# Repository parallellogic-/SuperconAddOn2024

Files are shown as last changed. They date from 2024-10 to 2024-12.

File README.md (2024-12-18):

# Luna Says Supercon Add-On Overview

This repo contains the project files for a Supercon Add-On (SAO) Printed Circuit Board (PCB) for Hackaday Supercon 2024, held November 1-3rd in Pasadena.

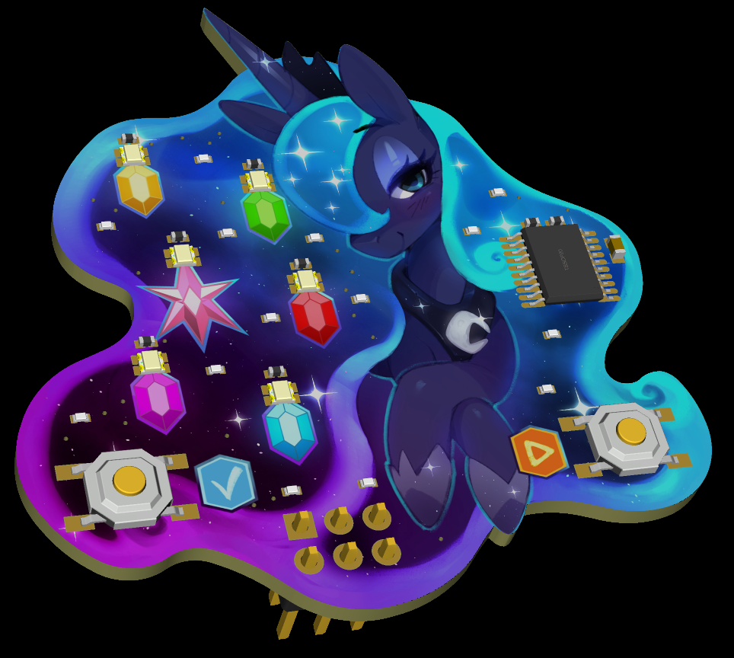
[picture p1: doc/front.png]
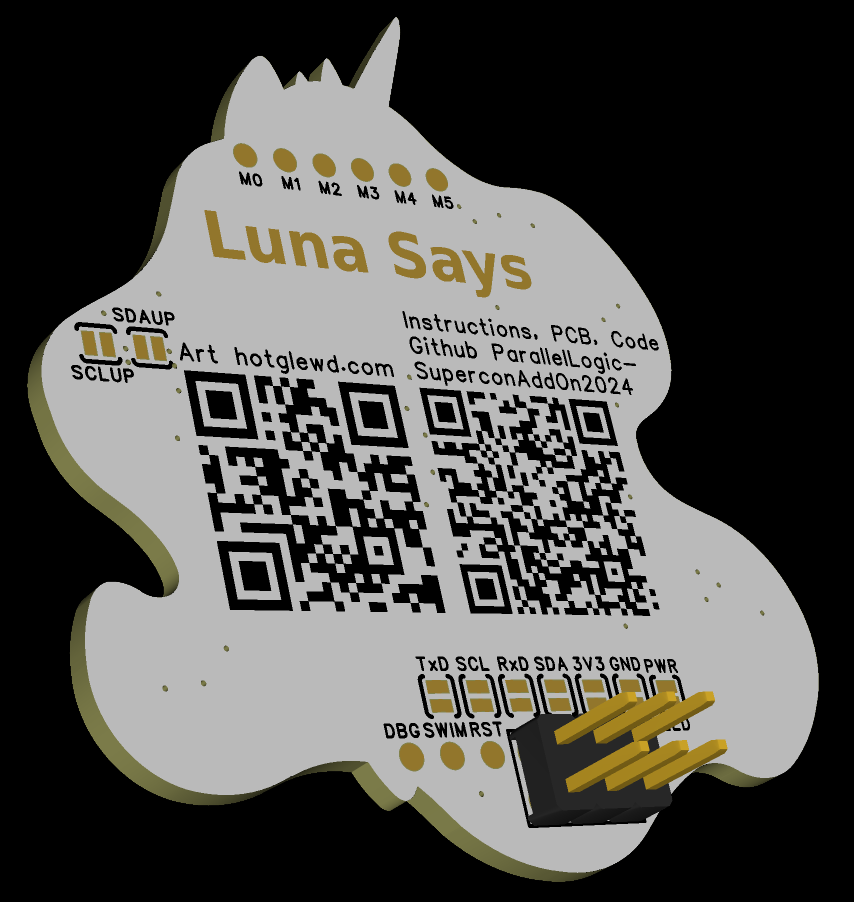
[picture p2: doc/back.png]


# User Guide

By default, when the unit is powered ON, the LEDs will display a random screen-saver display pattern on the white LEDs.

Pressing either button enters into a "Luna Says" game:
- Luna will highlight one of the Elements of Harmony (RGB LEDs)
- You must repeat the pattern that Luna has shown.  Press the right button to move the cursor and the left button to select the same Element of Harmony.
- When you highlight the correct gem, Luna's mane will flash green and she will then highlight one more gem than before.
- You must then highlight the same gems in the same order with progressively longer patterns.
- If you fail to repeat the pattern correctly, the LEDs will flash red and the game will reset from the beginning.
- The game is won by highlighting all the Elements of Harmony

Long pressing either button will enter in a Cyclone game:
- The Element of Harmony will spin in a circle
- You must press either button the moment the element passes the white marker
- When timed correctly, the central marker and two neighboring LEDs will alternately blink.  Pressing the button again will start the next (faster) level
- Failing to time the press accurately will flash the LED where the cursor landed.  Pressing the button again will restart the current level.
- The game is won by clearing all 6 levels

# Examples

## Idle

Random screen-saver idle display pattern



## Luna Says

Luna highlights the Elements of Harmony in a specific order.  You must repeat her pattern.

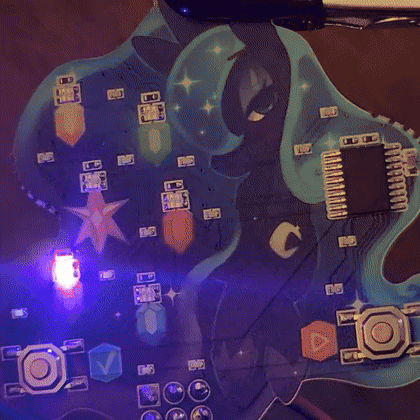
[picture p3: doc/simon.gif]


## Cyclone

The Elements of Harmony spin and you must catch each one at the right moment

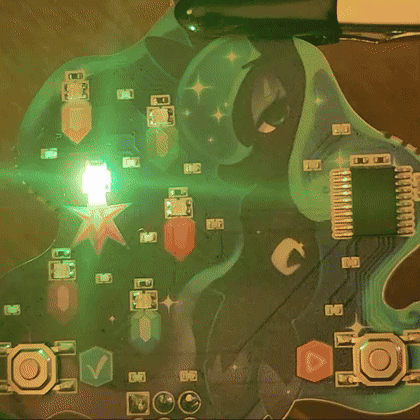
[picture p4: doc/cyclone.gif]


# Design

The state of the SAO may be read (buttons) and written (LEDs) using the I2C serial connection.

There are 6 pins on the SAO interface.  Two are used for 3V3 and GND power input.  Two are used for I2C.  The remaining two serve as SAO output event flags for button and frame-render-complete events.

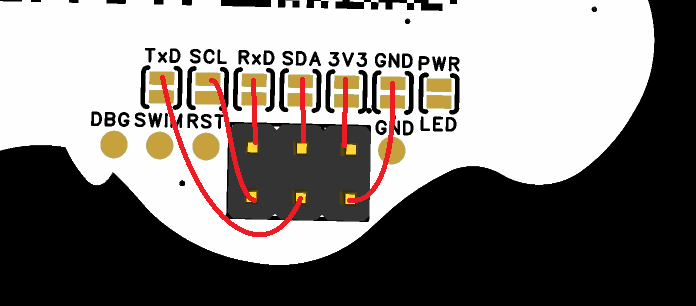
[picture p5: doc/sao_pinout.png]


| Pinout | | |
|---|-----|-----|
| GPIO1  | SDA | 3V3 |
| GPIO0  | SCL | GND |

The routing of the interface signals on the SAO header may be re-directed by cutting the associated trace and soldering jumper wires to the desired configuration.  The example below shows cutting (ex. with an exacto knife) the SDA and SCL traces (red) and then soldering jumper wires to swap the SDA and SCL lines (green and blue) on the I2C bus.

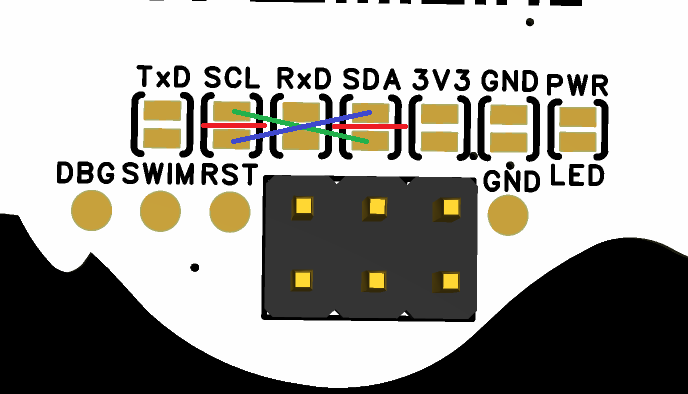
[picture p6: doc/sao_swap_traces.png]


Soldering the "PWR" jumper closed will permanently turn ON the dedicated power LED.

The I2C data and clock lines each have a 10kohm pull up resistor to 3V3 connected.  This can be disabled by cutting the traces here:

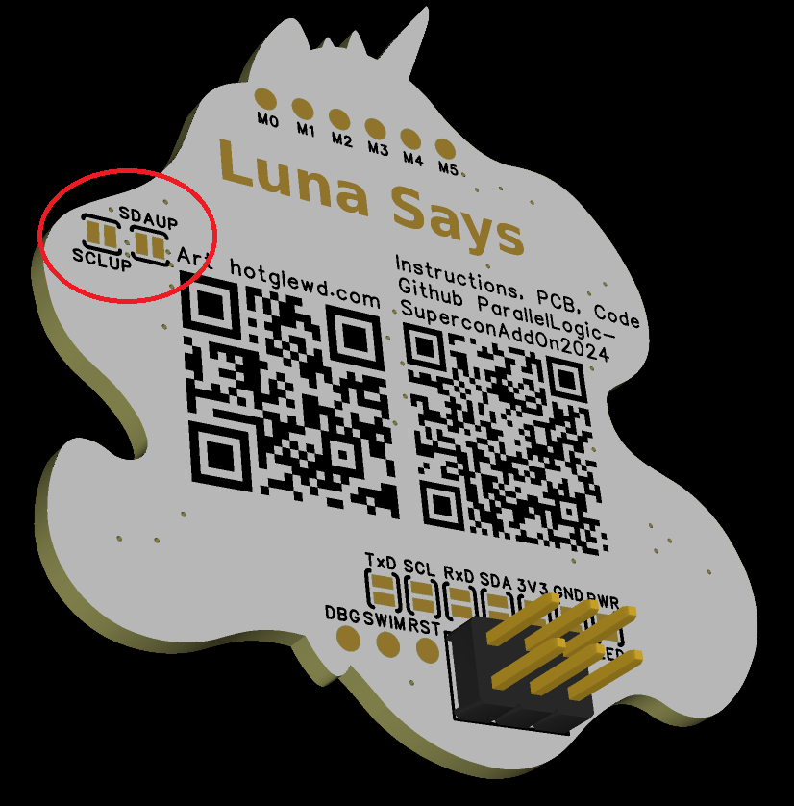
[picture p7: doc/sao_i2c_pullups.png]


There are two buttons and 31 LEDs (the RGB LED consists of three colors each that can be individually controlled).  30 of the LEDs are driven by 6 pins in a charlieplexed configuration.  The remaining debug LED, buttons, and serial interface are assigned dedicated pins on the processor.

| | 0 | 1 | 2 | 3 | 4 | 5 | Positive |
|---|---:|---:|---:|---:|---:|---:|---|
| 0 | | 20 (w7)  | 21 (w8)  | 4 (r4) | 5 (r5) | 6 (r6) | |
| 1 | 22 (w9)  | | 23 (w10) | 10 (g4)  | 11 (g5)  | 12 (g6)  | |
| 2 | 24 (w11) | 25 (w12) | | 16 (b4)  | 17 (b5)  | 18 (b6)  | |
| 3 | 1 (r1) | 2 (r2) | 3 (r3) | | 26 (w13) | 27 (w14) | |
| 4 | 7 (g1) | 8 (g2) | 9 (g3) | 28 (w15) | | 29 (w16) | |
| 5 | 13 (b1)  | 14 (b2)  | 15 (b3)  | 30 (w17) | 31 (w18) | | |
| Negative | | | | | | | |

| | PORT | PIN |
|---|---|-----|
| MAT0  | C | 3 |
| MAT1  | C | 4 |
| MAT2  | C | 5 |
| MAT3  | C | 6 |
| MAT4  | C | 7 |
| MAT5  | D | 2 |
| DEBUG | A | 3 |
| BTN0  | D | 3 |
| BTN1  | D | 4 |
| SWIM  | D | 1 |

# API

An example program that interfaces with the SAO over I2C (reading button state and setting LEDs) can be found [here](/src/Arduino_I2C_Master/Arduino_I2C_Master.ino)

SAO device 7-bit address is 0x30.  The baud rate is 100 kHz.

| Register Map | R/W | Title | Default | Range, Inclusive | Notes |
|:---:|:---:|:---:|:---:|:---:|:---:|
| 0 | R/W | Dummy | 0 | 0x00-0xFF | Values written here will echo back the same when read.  Reading this register will toggle the state of the debug LED. |
| 1 | R/W | Write Count | 0 | 0x00-0xFF | Counter of the number of I2C write transactions since power ON, value will roll-over above 0xFF.  Each read consists of 2 operations: a write (setting the register address) and a read (fetching the register contents) |
| 2 | R/W | Read Count | 0 | 0x00-0xFF | Number of I2C read transactions since power ON |
| 3 | W | LED Index | 0 | 0x00-0x1F | Writing an odd (>2) number of bytes to this register in single transaction is the same as writing alternately to registers 3 and 4,  with the final byte being written to register 5 |
| 4 | W | LED Brightness | 0 | 0x00-0xFF | 0 is OFF, 0xFF is max |
| 5 | W | Effective LED Count and LED Buffer Flush | 0 | 0x00-0x10 | Higher values are possible, but cause LED flickering and latency with button events |
| 6 | R/W | Button Interrupt Config | 0x03 | 0x00-0x03 | 0x01 (LSB) set to 1 means GPIO0 will be HIGH the moment the buttons are pressed (instantaneous), 0x02 set to 1 means GPIO0 will go high any  time there is a button event ready (short or long on the left or right  button).  0x03 sets GPIO0 HIGH any time either condition is true. If no  interrupt is triggered, then the pin is driven LOW.  Note: on first  power ON, until a valid I2C command is received, this pin floats |
| 7 | R | Peek button events | 0 | 0x00-0xF7 | 0x01 (LSB) is left button instantaneously down (0 is unpressed), 0x02 is right button instantaneously down, 0x04 is SWIM pin, 0x08 is unused, 0x10 is short press event flag on left button, 0x20 is short press on right button flag, 0x40 is long press on left button flag, 0x80 is long press on right button event flag |
| 8 | R | Pop button events | 0 | 0x00-0xF7 | Same as above, but upon read, the event flags (most significant nibble) are cleared |

## Buttons

Each button is monitored for short (>50 ms, <500 ms) and long (>500 ms) button presses.  These events are flagged when the button is released.  Only one event is flagged upon button release (a long press does NOT raise a short press flag).

GPIO0 acts as a button interrupt output.  The pin floats on power-ON.  After a valid I2C command is received GPIO0 is pulled low until an event occurs at which point it is pulled high until the event is resolved.  The configuration of the interrupt behavior can be set in the Button Interrupt Config register

| Function | Direction  | STM8 | PCB | SAO |
|---|---|---|-----|---|
| Button Interrupt | SAO Output | PD5  | TXD | GPIO0 |
| Frame Flag | SAO Output | PD6  | RXD | GPIO1 |

## LEDs

LEDs are indexed 0 to 31 per the below mapping.  Generally, RGB LEDs are indexed in a clockwise pattern, while white LEDs are numbered top-to-bottom and left-to-right.  The debug LED is located near the bottom

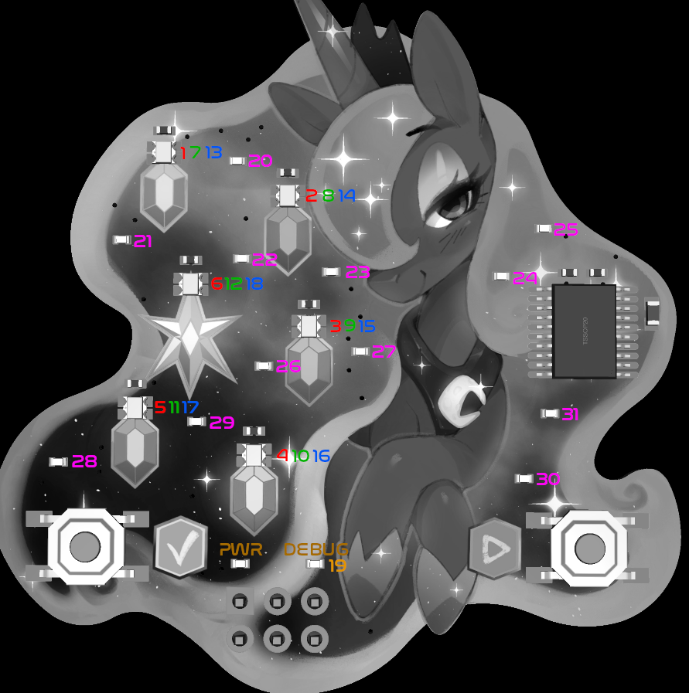
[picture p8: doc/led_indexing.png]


### LED operation

Note: The 8-bit LED brightness value is squared inside the SAO and then shifted down to a 10-bit value to better match the sensitivity of the human eye.  As such, some neighboring brightness values below 32 are non-unique and map to identical brightnesses.

Setting of an LED always requires two steps: one (or more) commands to set the brightness of the target LED(s), followed by one command to flush the LED buffer to the update interrupt routine.

Setting the brightness of one LED requires two bytes: one to specify the index (0 to 31 inclusive) and a second to set the brightness (0 to 255, inclusive, 255 is max brightness)

Producing a frame can be achieved in two ways:

1. Writing the LED index to register 3, writing the brightness to index 4, then sending additional writes to 3 and 4 for additional LEDs.  Finally a write is sent to register 5 with the effective number of LEDs.  This is a simpler approach but requires additional overhead on the I2C serial link



2. Performing a multi-byte write to register 3.  Since the index-brightness-index-brightness... bytes alternate and are followed by a single byte for the effective number of LEDs, there will always be an odd number of bytes in a compelte multi-byte transaction.



Note: Because the writing of a new frame may be completed faster than the time to illuminate the LEDs in the frame, and the SAO has only a single-frame buffer, GPIO1 is used as a busy flag: raised HIGH when a frame begins display and driven LOW when the frame has completed and the SAO is ready for a new frame.  To avoid shearing mid-frame, it is recommended to monitor GPIO1 to be in a LOW state before sending a new frame of data to the SAO.



Note: In the absense of an external command, the SAO will continue looping, showing the last frame flushed.

Note: Because the brightness is squared and because brightness is based on the time each LED spends ON, one LED at brightness 255 is equivalent to two LEDs at 180 brightness (255<sup>2</sup> ~= 2 * 180<sup>2</sup>).  This can be extended further, ex. to three LEDs at 147 brightness (255<sup>2</sup> ~= 3 * 147<sup>2</sup>) or in fractional combinations (ex. when shifting through a rainbow hue).  Rather than sleeping during the unused brightness period (to stablize the brightness regardless of whatever brightness each LED is configured to frame-to-frame), the sleep time can be skipped or reduced by setting an "effective" number of LEDs when flushing the frame buffer (on the supposition that the cumulative time each LED will spend ON will not exceed the equivalent amount of time a smaller number of LEDs would be ON for).  Thus, when some LEDs are displayed at partial brighntess, it may be possible to flush the display with an effecitve number of LEDs that is lower than the physcial number of LEDs being illuminated.

# Resources

- Artwork by http://hotglewd.com
- JLCPCB Multi Color Silkscreen Specification https://jlcpcb.com/help/article/How-to-design-multi-color-silkscreen-using-EasyEDA
- Contest Specifications https://hackaday.io/contest/197237-supercon-8-add-on-contest/details
- SAO Standard https://hackaday.io/project/175182-simple-add-ons-sao
- Schematic:

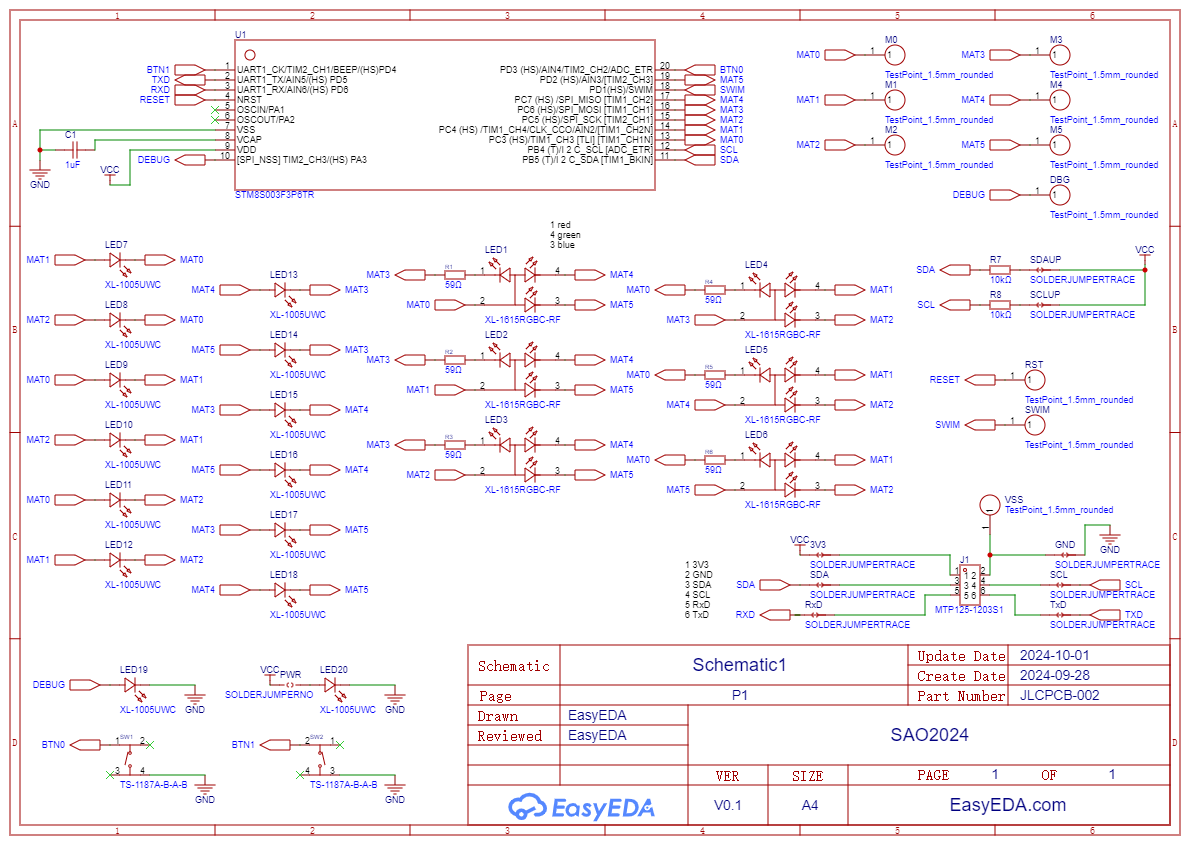
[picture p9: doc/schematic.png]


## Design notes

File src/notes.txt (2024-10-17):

STM8 programming reference: https://hackaday.io/project/161239-stm8s-development-board
STM8 programmer setup: https://circuitdigest.com/microcontroller-projects/getting-started-with-stm8s-using-stvd-and-cosmic-c-compiler
Including Cosmic C license request (allow 2 business days to get a key) ref. https://github.com/NevynUK/The-Way-of-the-Register

STM8S003F3P6TR processor
https://jlcpcb.com/partdetail/C52717
Basic white led https://jlcpcb.com/partdetail/Hubei_KentoElec-KT0603W/C2290

copied empty project from 2023
added in i2c lib from STM8S103F3_SPL-master

TODO: blink LED

--

Compiling stm8s_i2c.c...
cxstm8 +debug -pxp -no -l +mods0 -pp -i"C:\Program Files (x86)\COSMIC\FSE_Compilers\CXSTM8\Hstm8"  -clDebug\ -coDebug\ stm8s_i2c.c 
#error cpstm8 C:\Program Files (x86)\COSMIC\FSE_Compilers\CXSTM8\Hstm8\mods0.h:1 FlexLM Feature has expired.
stm8s_i2c.c:
 The command: "cxstm8 +debug -pxp -no -l +mods0 -pp -i"C:\Program Files (x86)\COSMIC\FSE_Compilers\CXSTM8\Hstm8"  -clDebug\ -coDebug\ stm8s_i2c.c " has failed, the returned value is: 1
exit code=1.

luna.elf - 3 error(s), 0 warning(s)

--> cosmic c license expired

STVP set to STM8S003F3

set from debug to release build

--

bug in RGB display was in the set_hue_max method - was dividing by too much and losing the fractional brightness of the target led, so only get 2-bit color in defcon badge
nixed the precision millis() function and dropped TIM2 into 16-bit timer functionality

*put yes/no/immedaite on gray/green/rey arrows in flow diagram
star=start entry to diagram

define what acryonms mean

--

1010 1010 1010
 *   
  **

0.000002 sec per count
6144 counts per frame (1024 counts at 6 leds)
/512
~=ms 1khz

12 ms/frame --> 80 FPS

---

Note that Arduino and STM8 disagree on addresses accroding to chatGPT and verified in HW
Arduino is sending on 0x30 and STM receives on 0x18.  oscope reads as 0x30

Make sure the STM8 is using the correct I2C address. The Arduino sends 0x30, which corresponds to 0x18 (since the last bit is used to indicate read/write in I2C).

    Shift Address: Some I2C libraries require you to shift the 7-bit address left by 1 bit when setting it up. For example, the STM8's I2C peripheral might expect 0x18 as the slave address, which is 0x30 when shifted left and combined with the R/W bit.

---

	// Check for Address Matched Event
    if (I2C_CheckEvent(I2C_EVENT_SLAVE_RECEIVER_ADDRESS_MATCHED))
    {
        //registerIndex = 0;  // Reset index on address match
        I2C_AcknowledgeConfig(I2C_ACK_CURR);
    }
    
    // Check for Data Received (in Receive mode)
    if (I2C_CheckEvent(I2C_EVENT_SLAVE_BYTE_RECEIVED))
    {
        /*if (registerIndex < NUM_REGISTERS)
        {
            i2cRegisters[registerIndex++] = I2C_ReceiveData();  // Store data into register
        }
        else
        {
            uint8_t dummy = I2C_ReceiveData();  // Receive, but ignore extra bytes
        }*/
				I2C_ReceiveData();//if not done, whole system locks up.  if is done, then only stm8 lcoks up
        //I2C_AcknowledgeConfig(I2C_ACK_CURR);  // Send ACK
    }
    
    // Check for Data Request (in Transmit mode)
    if (I2C_CheckEvent(I2C_EVENT_SLAVE_TRANSMITTER_ADDRESS_MATCHED))
    {
        //I2C_SendData(i2cRegisters[registerIndex++]);  // Send data from the current register
				I2C_SendData(0xDE);
    }

    // Check for Byte Transmitted (continue sending remaining data)
    if (I2C_CheckEvent(I2C_EVENT_SLAVE_BYTE_TRANSMITTED))
    {
        /*if (registerIndex < NUM_REGISTERS)
        {
            I2C_SendData(i2cRegisters[registerIndex++]);  // Send next byte
        }
        else
        {
            I2C_SendData(0x00);  // If index exceeds, send 0s
        }*/
				I2C_SendData(0xAD);
    }

TODO: watchdog 
--> watchdog has a max of 127/(16 MHz) ~= 8 milliseconds but want like 0.5 seconds

-- 10/14/24

surprised how small it is - could have made larger for free (min size with rails is 70mm square for full color silk screen)
white silkscreen avoce artwork on front (wasn't planned, presumably needed for part placement?)
cautious to break off mouse bites
would have been better to laser cut a sample to check the scale
barely plugged vias, minuscule light through vias, 100 mil header is clean
rgb sillkscreen extendsd under parts - silkscreen is done before part reflow
hard to test uart/i2c with current programmer configuration (without de-solder/re-soldering header multiple times)
***yellow color on RGB looks dirty...

- Kinda surprised how small they are.  They're the size I designed them to be, I just never made a mock-up to get an idea of the dimensions
- They left a bit of while silkscreen around each part, which irks me a bit, I know I didn't have that in the design files (if I did, it would have come out as black).  I suspect that's a technical limitation of whatever process they use (can only get color so close to the pads or something)
- Buttons and LEDs work, no issue

***refactor debug led coming on when all others are off

users think the colored gems are rockets

*need a diagram illustrating what I did (design/layout) vs others (art, fab, delivery) - illustrative cartoons to show what each stage looks like

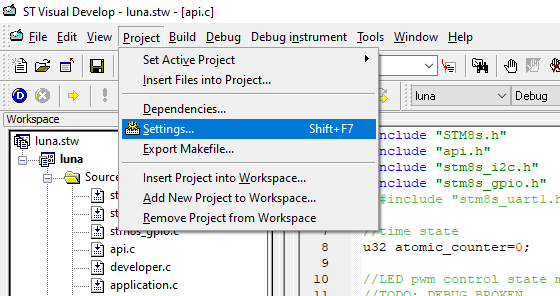
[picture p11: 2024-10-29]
doc/cosmic_c_download_more_ram_0.png

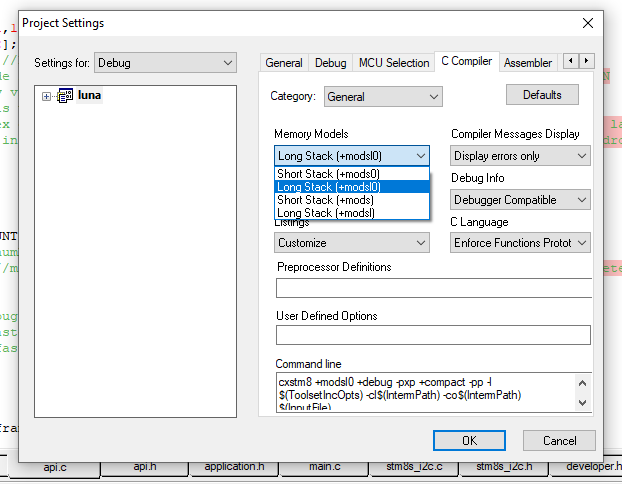
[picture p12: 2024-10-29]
doc/cosmic_c_download_more_ram_1.png

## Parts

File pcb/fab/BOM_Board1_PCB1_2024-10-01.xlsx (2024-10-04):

No. | Quantity | Comment | Designator | Footprint | Value | Manufacturer Part | Manufacturer | Supplier Part | Supplier
1 | 8 | SOLDERJUMPERTRACE | 3V3,GND,RxD,SCL,SCLUP,SDA,SDAUP,TxD | SJ_2S-TRACE
2 | 1 | 1uF | C1 | C0603 | 1uF | CL10A105KB8NNNC | SAMSUNG(三星) | C15849 | LCSC
3 | 10 | TestPoint_1.5mm_rounded | DBG,M0,M1,M2,M3,M4,M5,RST,SWIM,VSS | TESTPOINT_1.5MM_ROUNDED_SMD
4 | 6 | XL-1615RGBC-RF | LED1,LED2,LED3,LED4,LED5,LED6 | LED-ARRAY-SMD_4P-L1.6-W1.5-BR_XL-1615RGBC-RF |  | XL-1615RGBC-RF | XINGLIGHT(成兴光) | C965840 | LCSC
5 | 14 | XL-1005UWC | LED7,LED8,LED9,LED10,LED11,LED12,LED13,LED14,LED15,LED16,LED17,LED18,LED19,LED20 | LED0402-RD_YELLOW |  | XL-1005UWC | XINGLIGHT(成兴光) | C20613596 | LCSC
6 | 1 | SOLDERJUMPERNO | PWR | SJ_2S-NO
7 | 6 | 59Ω | R1,R2,R3,R4,R5,R6 | R0402 | 59Ω | RTT0259R0FTH | RALEC(旺诠) | C159005 | LCSC
8 | 2 | 10kΩ | R7,R8 | R0402 | 10kΩ | 0402WGF1002TCE | UNI-ROYAL(厚声) | C25744 | LCSC
9 | 2 | TS-1187A-B-A-B | SW1,SW2 | SW-SMD_4P-L5.1-W5.1-P3.70-LS6.5-TL-2 |  | TS-1187A-B-A-B | XKB Connectivity(中国星坤) | C318884 | LCSC
10 | 1 | STM8S003F3P6TR | U1 | TSSOP-20_L6.5-W4.4-P0.65-LS6.4-BL |  | STM8S003F3P6TR | ST(意法半导体) | C52717 | LCSC

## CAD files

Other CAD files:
cad/stand_v3.FCStd
src/empty_project/empty.stp
src/sao2024/luna.stp
cad/stand_v2.FCStd
cad/stand_v1.FCStd

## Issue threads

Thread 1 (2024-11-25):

debug LED blink on S8 Badge poweron

chaseadam, 2024-11-25:
S8 badge https://github.com/Hack-a-Day/2024-Supercon-8-Add-On-Badge/tree/main/hardware

my guess is it has something to do with the state of the non-power SAO header pins which is putting the device into a debug/programming mode indicated by a blinking Debug LED.

Attaching the SAO after S8 Badge poweron does not result in the same behavior.

This is very reproducible.

Is it possible to us the UART lines to reprogram the STM8?

chaseadam, 2024-11-25:
It appears to start the screensaver, but then switches to blinking debug LED.

It occurs when GPIO pins are not connected as well (just power and I2C)

chaseadam, 2024-11-25:
I suspect this comment indicating the app will stop when it receives a valid I2C packet is the culprit

https://github.com/parallellogic-/SuperconAddOn2024/blob/88335f758e7a8f4b2c9e10e32ae3f134e9ea2fbe/src/sao2024/main.c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

but seems after the application it switches to "developer mode" which seems to only activate the Debug LED once during setup

https://github.com/parallellogic-/SuperconAddOn2024/blob/88335f758e7a8f4b2c9e10e32ae3f134e9ea2fbe/src/sao2024/developer.c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

The only other area which I could think is causing the blink is in the API code:

https://github.com/parallellogic-/SuperconAddOn2024/blob/88335f758e7a8f4b2c9e10e32ae3f134e9ea2fbe/src/sao2024/api.c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

The debug LED appears to be controlled by `set_debug()`

chaseadam, 2024-11-26:
After exiting the main loop of the badge after startup with CTRL+C on the Micropython console, I noted the debug LED toggles when an I2C message is received (i.e. when I execute `which_bus_has_device_id(0x30, debug=True)`.

Looks like the main loop of the S8 badge is sending several I2C messages on startup. I let it run a bit longer and noticed it blinks for a few seconds and then happens to stop with the Debug LED solid on.

chaseadam, 2024-11-26:
This appears to be working as expected, but would be nice to be able to "re-enter" the `run_application()` with the buttons.

parallellogic-, 2024-12-03:
Ah!  I'm terribly sorry, I didn't see your message.  Apologies, yes, this is unfortunately the intended behavior.  I wanted the badge to be in the default application mode (screen savers + games) until it received any valid I2C command, in which case it would be immediately apparent to the operator it was responding immediately to (any and all) operator input.  However, the default badge behavior (I didn't learn about until arriving at the con) pings all the I2C devices on power-up, which puts this SAO into developer mode as you've noted.  If you configure the badge to skip over the 0x30 device address, this should bypass the offending action and allow the device to remain in application mode.  Alternatively, if you hold down the boot button on the badge during power-ON, it will hold the badge in reset, applying power to the SAOs without any I2C traffic, which also allows the SAO to remain in application mode too.

_Attaching the SAO after S8 Badge poweron does not result in the same behavior._
The badge only queries the I2C bus for SAO addresses on boot-up, which is the problem area

_Is it possible to us the UART lines to reprogram the STM8?_
I don't have any provisions for that, sorry (the UART was a feature I nixed as redundant once it became apparent the I2C bus was fast enough to flush full frames at 60+ Hz).  I programmed these using the SWIM+RESET pins and an [ST-LINK/V2](https://botland.store/programmers/14281-st-linkv2-in-circuit-debugger-programmer-for-stm8-and-stm32-5904422342432.html), though I fully expect a ST-Link should work just as well https://www.amazon.com/CANADUINO-Compatible-Circuit-Programmer-Debugger/dp/B07B2K6ZPK

_I noted the debug LED toggles when an I2C message is received_
That's precisely the intended behavior!  Trying to give the developer visual feedback during initial boot-up of the I2C bus with this SAO.  Note the I2C API on the main page for additional commands: https://github.com/parallellogic-/SuperconAddOn2024/tree/main

_This appears to be working as expected, but would be nice to be able to "re-enter" the run_application() with the buttons_
Thank you for your feedback.  I did expose the buttons over the I2C API too, so there'd be contention between reading the button state/events as an input for relay over I2C vs taking action based on button pushes.  For future reference, what would you think of an I2C command to revert an SAO like this back to application mode?  One implementation could have the badge query the state of the buttons and then send the appropriate I2C command to revert to application mode.

Closed 2024-11-26.

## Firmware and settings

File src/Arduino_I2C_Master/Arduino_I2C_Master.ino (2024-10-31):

//the following code is an example i2c master that demonstrates how to write to the LEDs and read the button states
//will print "START" to the terminal and then will be begin one of the two demos included:
//loop_slow() will use one-byte-at-a-time transactions to set each LED
//loop_fast() will use a multi-byte transaction to set and flush all LEDs at once (and will wait for frame to finish before immediatley sending another one), ~80 FPS

//connections: SDA, SCL, 3V3, GND.  For loop_fast(), connect the SAO RX pin, (SAO GPIO1) to FRAME_INTERRUPT_PIN on the ARDINO
//NOTE: GPIO0 and GPIO1 are floating by default.  Events will only be flagged (output from SAO36) once a valid I2C transaction has been received

#include <Wire.h>
#define SLAVE_ADDRESS 0x30  // SAO slave address

uint8_t buff[257];//array to hold data going to /fram the SAO
uint8_t buff_len=0;//length of array
int frame=0;//frame counter tracking how many frames have been sent to the SAO
const int FRAME_INTERRUPT_PIN=3;

void setup()
{
    Wire.begin();          // Initialize I2C as master
    Serial.begin(1000000);    // Initialize Serial for debug output, note that low-end processors may need a lower speed baud rate
    delay(4000);//ensure PC has serial monitor visible
    Serial.println("START");
    pinMode(LED_BUILTIN,OUTPUT);
    pinMode(FRAME_INTERRUPT_PIN,INPUT);//monitor frame-done interrupt (HIGH when SAO is busy, LOW when frame hrendering has completed)
}

void loop()
{//choose which demo to see
  //loop_slow();//toggles between 3 red LEDs ON, and 3 green LEDs ON, every second
  loop_fast();//fades all 6 red LEDs in/out, then fades green in/out, then blue, then repeats
}

void loop_fast()
{
  digitalWrite(LED_BUILTIN,0);
  api_write_leds_continuous();
  digitalWrite(LED_BUILTIN,1);
}

void loop_slow()
{
  digitalWrite(LED_BUILTIN,0);
  api_write_leds_slow();
  delay(500);  // Wait before repeating
  digitalWrite(LED_BUILTIN,1);
  delay(500);  // Wait before repeating
}

void api_read_buttons()
{
  uint8_t set_button_interrupts=4;//apriori invalid value, will be set to valid value later.  This is the button interrupt config register value
  uint8_t read_reg=7;//read button state from this register
  if(Serial.available())
  {//user command to clear events
    read_reg=8;//if a serial command is seen, then read buttons from one address high, which clears the button event flags (clear short/long press event flags)
    switch(Serial.read())
    {
      case '0': set_button_interrupts=0; break;//nothing triggers button interrupt
      case '1': set_button_interrupts=1; break;//interrupt only echos instantaneous button state (low for no presses, high for any press)
      case '2': set_button_interrupts=2; break;//interrupt only is high when there is a complete event (short or long on either button) ready
      case '3': set_button_interrupts=3; break;//combo of 1 and 2 above (high for either instantanous or event-ready)
    }
    if(set_button_interrupts<4)
    {//if there is a valid command to change the button interrupt behavior, execute the request here
      buff[0]=set_button_interrupts;//new button interrupt setting
      buff_len=1;
      writeToRegister(6);//register that holds the interrupt setting
    }
  }
  readFromRegister(read_reg,1);//query SAO for button state (and clear events if desired)
  
  Serial.print("Read Device: 0x");
  Serial.print(SLAVE_ADDRESS, HEX);
  Serial.print(" | Read Register: 0x");
  Serial.print(read_reg, HEX);
  Serial.print(" | Read value:");
  for(int iter=0;iter<buff_len;iter++)
  {
    Serial.print(" 0b");
    for (int rep = 7; rep >= 0; rep--) {
      Serial.print((buff[iter] >> rep) & 1);
      //bit 0 (LSB) is left button instantaneous state
      //bit 1 is right button
      //bit 2 is SWIM pin state
      //bit 3 is unused
      //bit 4 is left button short press event flag
      //bit 5 is right button short press flag
      //bit 6 is left button long press flag
      //bit 7 (MSB) is right button long press flag
    }
  }
  Serial.println();
}

void api_write_leds_continuous()
{
  if(digitalRead(FRAME_INTERRUPT_PIN)) return;//wait while SAO is still working on last command (let it finish rendering the last frame to avoid overwriting data)
  frame++;
  uint8_t write_reg=3;//register where to stream LED info to
  long tms=millis()>>2;//for demo purposes, use time as a state machine to determine what pattern to display
  int count=0;//LED index
  int loop_count=6;//number of LED LEDs to light up
  int color_offset=((tms>>9)%3)*6;//cycle through each of the three colors in RGB
  for(int iter=0;iter<loop_count;iter++)
  {
    buff[iter*2]=iter+color_offset;//after each fade in/out, proceed to the next RGB color
    buff[iter*2+1]=((tms>>8)&0x01?~tms:tms)&0x000000FF;//fade in/out the LED brightness - all LEDs are given the same brightness in this demo
    if(buff[iter*2+1]) count++;//count up the number of LEDs iluminated
  }
  buff[loop_count*2]=loop_count;//last byte of transaction is the number of LEDs (transaction must be an odd number of bytes to auto-trigger the led_flush function)
  buff_len=loop_count*2+1;
  writeToRegister(write_reg);
  api_read_buttons();
  Serial.print("Frame: ");
  Serial.println(frame);
}

//alternately illuminate red LEDs ad different rbightenesses, or green LEDs
void api_write_leds_slow()
{//this appraoch is slow because it entails a different transaction for each LED index, brightness, and flush operation.  The stream operation performed in the api_write_leds_continuous() method above is faster because all data is written and set in a single i2c transaction
  buff_len=1;
  uint8_t rg=0;
  if(millis()%2000>1000) rg=6;//every other second, change between green and red
  //write 
  buff[0]=0+rg; writeToRegister(3); Serial.print("Write Device: 0x"); Serial.print(SLAVE_ADDRESS, HEX); Serial.print(" | Write Register: 0x"); Serial.print(3, HEX); Serial.print(" | Write value:"); Serial.println(buff[0], HEX);//first LED index
  buff[0]=255;  writeToRegister(4); Serial.print("Write Device: 0x"); Serial.print(SLAVE_ADDRESS, HEX); Serial.print(" | Write Register: 0x"); Serial.print(4, HEX); Serial.print(" | Write value:"); Serial.println(buff[0], HEX);//first LED brightness
  buff[0]=1+rg; writeToRegister(3); Serial.print("Write Device: 0x"); Serial.print(SLAVE_ADDRESS, HEX); Serial.print(" | Write Register: 0x"); Serial.print(3, HEX); Serial.print(" | Write value:"); Serial.println(buff[0], HEX);
  buff[0]=147;  writeToRegister(4); Serial.print("Write Device: 0x"); Serial.print(SLAVE_ADDRESS, HEX); Serial.print(" | Write Register: 0x"); Serial.print(4, HEX); Serial.print(" | Write value:"); Serial.println(buff[0], HEX);
  buff[0]=2+rg; writeToRegister(3); Serial.print("Write Device: 0x"); Serial.print(SLAVE_ADDRESS, HEX); Serial.print(" | Write Register: 0x"); Serial.print(3, HEX); Serial.print(" | Write value:"); Serial.println(buff[0], HEX);//last LED index
  buff[0]=32;   writeToRegister(4); Serial.print("Write Device: 0x"); Serial.print(SLAVE_ADDRESS, HEX); Serial.print(" | Write Register: 0x"); Serial.print(4, HEX); Serial.print(" | Write value:"); Serial.println(buff[0], HEX);//last LED brightness
  buff[0]=3;    writeToRegister(5);//number of effective LEDs illuminated.  writing this value to the SAO flushes the LED buffer to the live display.  writing this multiple times will flush the display multiple times, leading to a blank display
  Serial.println();
}

void api_toggle_debug()
{
  uint8_t write_reg=0;//the first register is a place for dummy read/writes (will echo back the data written to it when read), and will toggle the debug LED on each read or write operation
  uint8_t read_reg=1;//registers 1 and 2 are a counter of the number of read and write operations performed (note 255 roll-over)
  buff[0]='a';//dummy data to write
  buff_len=1;
  writeToRegister(write_reg);
  delayMicroseconds(150);//allow a gap to separate the i2c transactions on the oscope
  readFromRegister(read_reg,2);//read 2 bytes: the number of read and write operations performed.  Note: a write transaction contails of one write (setting the address) and read (reading the data back)
  // Print the written and read-back values to the serial monitor
  Serial.print("Write Device: 0x");
  Serial.print(SLAVE_ADDRESS, HEX);
  Serial.print(" | Write Register: 0x");
  Serial.print(write_reg, HEX);
  Serial.print(" | Write value:");
  for(int iter=0;iter<buff_len;iter++)
  {
    Serial.print(" 0x");
    Serial.print(buff[iter], HEX);
  }
  Serial.println();
  Serial.print("Read Device: 0x");
  Serial.print(SLAVE_ADDRESS, HEX);
  Serial.print(" | Read Register: 0x");
  Serial.print(read_reg, HEX);
  Serial.print(" | Read value:");
  for(int iter=0;iter<buff_len;iter++)
  {
    Serial.print(" 0x");
    Serial.print(buff[iter], HEX);
  }
  Serial.println();
}

void writeToRegister(uint8_t registerAddress)
{
    Wire.beginTransmission(SLAVE_ADDRESS);  // Begin transmission to the STM8
    Wire.write(registerAddress);            // Specify the register to write to
    for(int iter=0;iter<buff_len;iter++) Wire.write(buff[iter]); // Write the data bytes
    Wire.endTransmission();                 // End the transmission
}

void readFromRegister(uint8_t reg,uint8_t byte_count) {
    Wire.beginTransmission(SLAVE_ADDRESS);  // Start communication with the sensor
    Wire.write(reg);                       // Send the register address
    Wire.endTransmission();                // End transmission, but keep the connection alive

    Wire.requestFrom(SLAVE_ADDRESS, byte_count);     // Request X byte(s) from the sensor
    uint8_t out=0;
    while(Wire.available()==0){}//wait for data to be available
    buff_len=0;
    while (Wire.available()) {
        buff[buff_len]=Wire.read();
        buff_len++;
    }
}

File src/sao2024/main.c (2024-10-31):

#include "STM8s.h"
#include "api.h"
#include "application.h"
#include "developer.h"

int main()
{
	setup_main();//setup GPIO, interrupts and I2C
	if(is_button_down(0) || is_button_down(1) || is_button_down(2)) hello_world();//if either button is pressed during boot, jump into an LED test mode
	run_application();//run application until a valid I2C command is received
	run_developer();//hold in developer mode
	return 0;
}

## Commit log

2024-10-10 blinking led
    [luna.stp]
2024-10-11 fading led
2024-10-11 crossfade 2 leds
    [luna.stp]
2024-10-11 crossfade 2 leds with led_lookup
2024-10-12 crossfade 2 leds prep for buffer
2024-10-12 triple led stable static
2024-10-12 legacy hardware 6-element rainbow test with 6 rgb and 2 white leds
2024-10-12 starting button rework
2024-10-14 working i2c read and write
2024-10-15 got final boards in-hand, moving to debug testing new hardware
    [empty.stp]
2024-10-17 programmed first unit
    [luna.stp]
2024-10-30 going to add a button interrupt config register
2024-10-31 commenting code
    [luna.stp]
2024-12-16 case v1
    [stand_v1.FCStd]
2024-12-16 revise stand to be longer
    [stand_v2.FCStd]
2024-12-18 draft 3 of stand
    [stand_v2.FCStd, stand_v3.FCStd]
